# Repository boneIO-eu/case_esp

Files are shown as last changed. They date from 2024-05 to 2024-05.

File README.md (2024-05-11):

# Case for boneIO ESP
The case is designed for 3D printing
* Recomended matirial PET-G
* Recomended color GRAY, for button BLUE

esp v0 6 case

# Compatibile with boards

|  | Case ESP v0.1 | Case ESP v0.2 - v0.5 | Case ESP v0.6 | Case ESP v0.7 - v0.8|
| :---: | :---: | :---: | :---: | :---: |
| input ESP v0.6| 🔴 | 🔴 | 🟢 | 🟢 |
| input ESP v0.5| 🔴 | 🟢 | 🔴 | 🟢 |
| input ESP v0.2 - v0.4  | 🟢 | 🟢 | 🔴 | 🔴 |
| relays boards | 🟢 | 🟢 | 🟢 | 🔴 |
| expansion board  | 🟢 | 🔴 | 🔴 | 🔴 |
| 1/2 relays boards| 🔴 | 🔴 | 🔴 | 🔴 |

# Bill of Materials for one case
| Name | pcs. | Notes|
| :---: | :---: | :---: |
| Front | 1 | printed |
| Middle  | 1 | printed |
| Bottom  | 1 | printed |
| Back  | 1 | printed |
| Button | 1 | printed |
| OLED Mount | 1  | printed |
| Clips  | 2 | purchased Gianta DxMG-WALL CLIP |
| Bolts| 8 | purchased  AN745 3x25 |

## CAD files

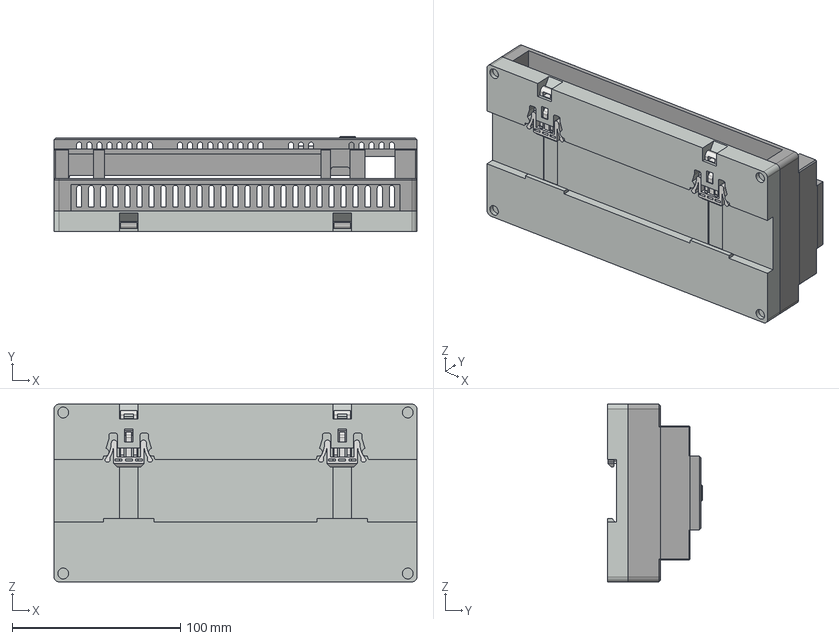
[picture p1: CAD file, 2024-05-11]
esp v0.8 case.step
216.0 x 56.8 x 105.8 mm
button v0.3
front case
back case
DXMG-WALL-CLIP x 2
front case slim
oled mount (1)

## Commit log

2022-04-09 Zmiana w froncie obudowy
    Podwyższenie całości o 0.5mm aby usunąć naprężenia
2022-05-25 front ESP v0.2
    [front ESP.stl]
2022-05-26 rename stl folder
    [back ESP.stl, front ESP.stl]
2022-07-24 Fixed scale of back ESP stl file
    [back ESP.stl]
2022-09-01 front v0.3
    [front ESP.stl]
2022-09-05 Front ESP v0.4
    Front ESP v0.4
    [front ESP.stl]
2022-09-19 back ESP v0.4
    fixed collisions with cover board
    [back ESP.stl]
2022-09-19 Delete Case boneIO ESP.stp
    outdated version
    [Case boneIO ESP.stp]
2024-01-10 esp case v0.5
    - changed clips to DXMG-WALL-CLIPGAINTA
    - modified ventilation holes
    - minor modifications
    [back ESP.stl, button.stl, esp case.step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]
2024-03-05 Update README.md
    Fixed bug in bill of materials
2024-03-18 switched to multipart case for better printing
    - split front case into 3 elements
    - added oled mount for better display installation
    [OLED mount.stl, back ESP.stl, bottom ESP.stl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]
2024-04-06 added backward compatibility for v0.5 input board
    - added backward compatibility for v0.5 input board
    - changed front piece for easier assembly
    - small changes in oled mount
    - some other minor changes
    [OLED mount.stl, back ESP.stl, bottom ESP.stl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]
2024-05-11 Added space for longer wt32 boards
    [esp v0.7 case.step, esp v0.8 case.step]
